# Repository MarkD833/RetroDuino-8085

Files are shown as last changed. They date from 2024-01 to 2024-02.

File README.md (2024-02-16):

# RetroDuino-8085

I've been toying with the idea of creating an 8085 based microprocessor board around the size of an Arduino UNO ever since I came across the [65uino](https://hackaday.io/project/190260-65uino) board on the hackaday website.

# Table of contents
* [The wish list](#the-basics-of-the-design)
  - [The Microprocessor](#the-microprocessor)
  - [ROM](#rom)
  - [RAM](#ram)
  - [Serial](#serial)
  - [I/O](#digital-input-output)
  - [ADC](#analogue-to-digital-converter)
* [Board Layout](#the-board-layout)
* [Assembly Instructions](#assembly-instructions)
* [The 16V8 GAL](#the-16v8-gal)
* [Pinout](#pinout)
* [Software](#software)
* [PCB Files](#the-board-design-files)
* [Known Errors](#known-errors)
* [History](#history)
## The basics of the design

I started off with some basics:
| Item | Notes |
| :---- | :---- |
| Microprocessor | an 8085 device but which one and what clock speed |
| ROM | At least 8K maybe 16K - but do I need that much?  |
| RAM | 32K would be good to aim for |
| Serial | 1 serial port but bit bang or hardware? |
| I/O | Bit programmable i/o |
| Analogue In | A multi channel ADC if there's room |
| LEDs | At least 1 user LED |

Oh, and one other requirement - no surface mount chips or hard to solder parts!

That's quite a lot to cram into the footprint on an Arduino UNO!

After a lot of playing around with an Arduino UNO prototyping board and various chip sockets I came up with a basic design and layout.

## The Microprocessor

The 8085 is mostly seen in a 40-pin DIL package. That's a huge amount of real estate on a footprint the size of an Arduino UNO. I discovered that OKI Semiconductor manufactured an 80C85 in a 44-pin PLCC package (MSM80C85AHGS-2K). After a quick bit of digging I located the datasheet and also a source on ebay that was selling some of the chips as NOS (New Old Stock).

Additional board space is consumed as the 8085 has a multiplexed address and data bus. The lower 8-bits are shared between D0..D7 and A0..A7 and an 8-bit latch (74LS573) is used to capture A0..A7.

Another design challenge is that the 8085 interrupts (if I were to use them) are active high rather than active low! 

The 8085 is clocked from an 11.0592MHz crystal, which gives an actual clock of 5.5296MHz (the 8085 divides the crystal frequency by 2). I've yet to experiment to see the effects of a higher frequency even though I'm exceeding the manufacturers 10MHz clock by 10% already.

## ROM

There are quite a few ROM devices available in a PLCC package as well, but I decided to go with a Winbond W27C512 64K x 8 EEPROM in a 28-pin DIL package. There's plenty for sale on ebay too. The reason for going the DIL package route will become clear with the choice of RAM device.

## RAM

I couldn't find any suitable RAM devices in PLCC format so the project success was looking rather bleak. Then I discovered that there were some SRAM devices available in DIL packages that were only 0.3in wide (called Skinny-DIP if I recall correctly). I then got lucky and sourced some UMC UM61512AK 64K x 8 SRAMs in a skinny 32-pin DIL package.

The RAM chip could sit underneath the ROM chip and I would save a lot of board space.

## Serial

I thought about bit banging the serial port using the SID and SOD pins of the 8085 but decided to try and go with real hardware. Again board space was at a premium so the hunt was on for a small UART device. A lot of serial chips have a large number of pins dedicated to various handshaking signals as well as synchronous data transfer - although some devices allow repurposing of these signals as discrete inputs or outputs. They are all still quite large chips in either PLCC or 0.6in DIL packages.

I then discovered a Philips SCC2691 UART (SCC2691AC1N24) that was available in a 0.3in wide 24-pin DIL package. It had an internal baud rate generator and a single 16-bit timer/counter as well. 

## Digital Input Output

I really wanted the I/O chip to have pin programmable direction control. That ruled out the 8155 and 8255 chips. It took a lot of searching but I then discovered a Zilog Z85C36. It had 2x 8-bit bit programmable I/O ports as well as 3x 16-bit timer/counters. That would be perfect!

Except that it wasn't! In my v1.0 design, I couldn't get the Z85C36 to respond at all. I don't know quite what the issue was as I was sure that I was meeting the timing requirements - but clearly something wasn't right.

In order to salvage the situation, I changed the I/O chip to a WDC W65C22S device. The chip still gave me 2x 8-bit bit programmable I/O ports, but only 2x 16-bit timer/counters.

## Analogue to Digital Converter

If I could fit it in, then an a National Semiconductor ADC0844 might work out - it's a 4 channel ADC in a 20-pin DIL package. 

# The board layout

There was quite a bit of massaging to get everything to fit as I also used a GAL16V8 to handle address decoding and interrupt inversion. The result was a board slightly longer than an Arduino UNO (but the same width).

This is an annotated 3D view of the board generated by Kicad as it stands at v1.2.

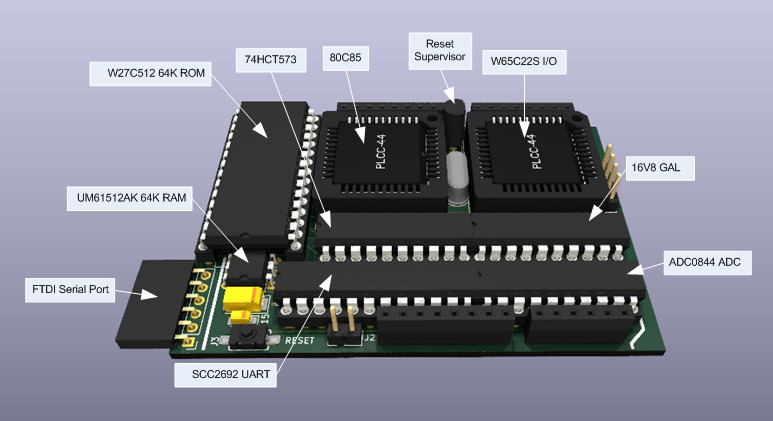
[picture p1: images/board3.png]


The thick white lines on the silkscreen just to the right of the FTDI serial port connector and the ADC0844 chip show the outline of an actual Arduino UNO board.

# Assembly Instructions

Assembly of the board is pretty straightforward with a few things of note.

1. Solder all the small SMD resistors and capacitors first - especially on the top of the board as there is very little room once the IC sockets are fitted.
2. Solder the microprocessor crystal and Reset device before fitting the 44-pin PLCC sockets otherwise you may find that the crystal will not fit down between the 44-pin PLCC sockets. 
3. Depending on the particular DIL socket(s) used for the SCC2691 UART, you may need to remove some of the plastic from the socket so that the 3.6864MHz crystal fits. I used 2 turned-pin sockets, an 8-pin and a 16-pin, to create the 24-pin socket needed. I found that the turned pin socket was less bulky than a regular socket.
4. The 28-pin DIL socket for the W27C512 ROM needs modifying. As the RAM chip will be sitting underneath the ROM chip, I removed the 3 pieces of plastic between the 2 rows of pins - effectively creating two separate 14-pin SIL sockets.
5. Lastly, solder the 4 SIL sockets. These pretty much seal off the top of the board for any further access with a soldering iron, so make sure that the board works before fitting thse. 

This is a photo of the RetroDuino-8085 board showing the location of the 3.6864MHz UART crystal and the modified 28-pin DIL socket.

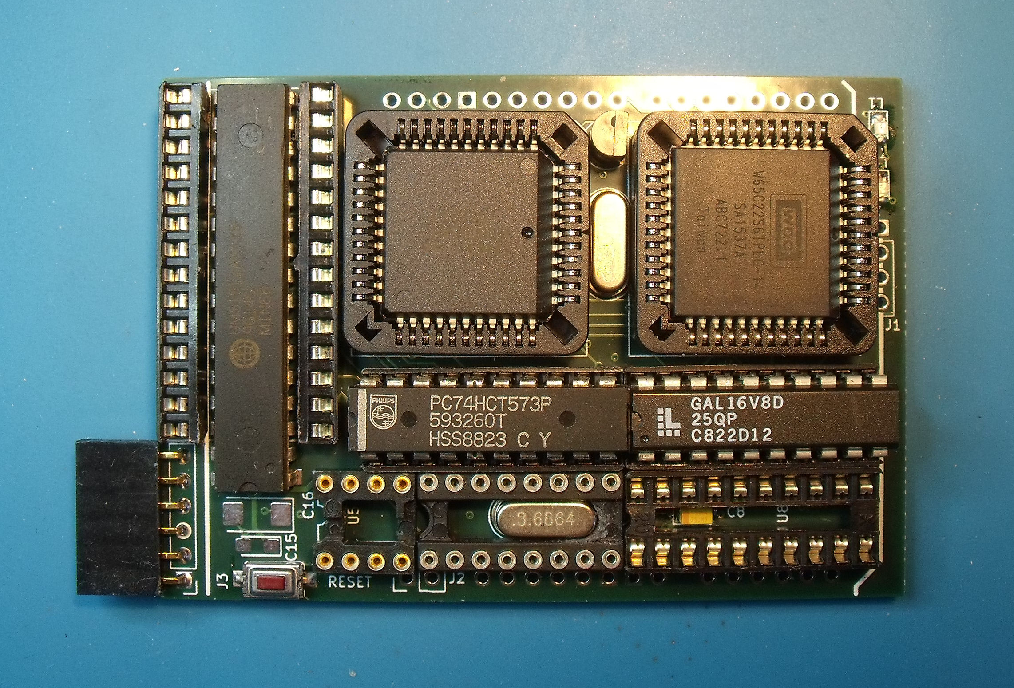
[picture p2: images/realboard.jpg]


# The 16V8 GAL

There's so little space on this board that a GAL seemed the logical choice to handle the usual discrete logic. The GAL does address and i/o decoding as follows:
* Memory space
  * 0x0000 - 0x3FFF selects the ROM
  * 0x4000 - 0xFFFF selets the RAM
* I/O space
  * 0x00 - 0x3F selects the SCC2692 UART
  * 0x40 - 0x7F selects the W65C22S digital i/o chip
  * 0x80 - 0xBF selects the ADC0844 ADC chip
 
In addition, the GAL inverts the SCC2692 and W65C22S interrupt signals.

Finally, the GAL has the ability to completely switch out the ROM to give access to the full 64K or RAM. The 8085 SOD pin is used to control this feature.

The GAL files are in the code folder.

# Pinout
Below is an image of the pinout I'm using - laid out in a similar way to the Arduino pinout diagrams found on the web. Note that the I2C and SPI signals will hopefully be generated by a software implementation of a hardware interface. 

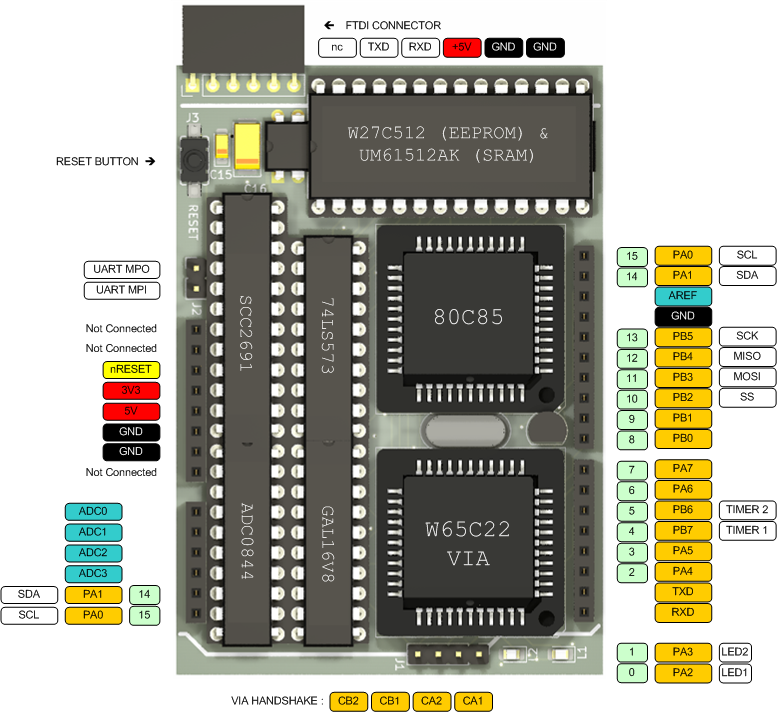
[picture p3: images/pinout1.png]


# Software

Please see the readme in the Code folder for more details on the software.

# The board design files

The board folder holds the gerber files that were sent to JLCPCB to make the board. It's a 4 layer board but small enough to get it made very cheaply.

The design was done using Kicad 7.0. I'm not sure exactly which files I need to share for the schematic and board layout so I've put the .kicad_pro, .kicad_sch & .kicad_sch files into the board folder. There's also the BOM as a CSV file showing the components used.

# Known errors

Yep, there are errors with v1.2. So far:
* LED D2 wrong way round
* LED D3 wrong way round

# History
* v1.2
  * Used ALE to clock the GAL rather than SYSCLK.
  * Removed the CompactFlash socket and associated passives.
  * Used 8085 SOD discrete to switch out the ROM.
  * Addition of 2nd user LED.
  * Repositioning of the FTDI connector.
* v1.1 
  * Updated design using the W65C22 PIA chip.
* v1.0
  * Initial design using the Z85C36 CIO chip.

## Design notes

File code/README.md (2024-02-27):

# RetroDuino-8085 Software

## The 8085 Monitor 
The MON85 folder contains a modified version of the excellent 8085 monitor called MON85 written by [Dave Dunfield](https://dunfield.themindfactory.com/). You can find the source code to the 8085 monitor along with monitors for other micros in the MONITORS.ZIP file on Dave's website. The monitor code needs tweeking to support the specific UART hardware I am using but that simply involves providing code to initialise the UART and code to output a characher/byte as well as read in a character/byte.

MON85 can be assembled using the free online assembler at [ASM80.COM](https://asm80.com) - select the 8080 CPU.

The MON85 user manual is also in the MON85 folder.

I've modified MON85 to work with the SCC2691 UART such that there are 2 versions of MON85 available:

| Software | Notes |
| :---- | :---- |
| MON85_ROM | Monitor runs in ROM and 48K RAM is available from 0x4000 - 0xFFFF. |
| MON85_RAM | Monitor runs in RAM and the whole 64K RAM is available but the monitor resides at 0x0000 - 0x1100. |

In addition, the MON85_ROM version has a small tweak. During initialisation, a small piece of code is copied from the ROM into RAM starting at address 0xFF80. Executing the code from MON85 with a "g FF80" command will disable the ROM (and MON85) and execute code starting at address 0x0000.
  
## A simple LED flasher
The LEDTest folder contains a simple piece of assembler code that flashes the 2 onboard LEDs. The code was assembled using the [ASM80](https://www.asm80.com/) online assembler. Set the CPU type to 8080 when creating the file. I've also put the listing file generated by ASM80 into the LEDTest folder along with the Intel-HEX file that can be loaded using MON85. The code is designed to load at address 0x5000 and run from that address.

## A simple LED flasher in RAM
The LEDTest2 folder contains the same simple LED flashing code as above, BUT demonstates an interesting feature. Note that this code should only be used with the MON85 ROM monitor - it won't work with the MON85 RAM monitor.

The MON85 monitor resides in ROM starting at address 0x0000. The downside of this is usually that you cannot put your own interrupt handlers there as it's Read Only. However, with the RetroDuino-8085 design, you can!

Using the MON85 L command, load the LEDTest2 Intel-HEX file. This will load the LED flashing code into RAM at address 0x0000. Even though the MON85 ROM resides in this area, MON85 can actually write to the RAM at the same address - it just can't read from that RAM. Any attempt to read from this area will read the ROM - i.e MON85.

In order to run the code, give MON85 the command "g FF80". There is a small piece of code that is pre-loaded by MON85 that resides at this address. This simple bit of code sets the 8085 SOD pin high - switching out the MON85 ROM completely - and then jumps to address 0x0000 to execute whatever code it finds there.

You can put whatever code you like into low memory and run it just like it would run from ROM.

The downside is that once the ROM is switched out, you loose all the MON85 capabilities like inspecting and modifying memory, setting breakpoints etc.

# z88dk - The z80 development kit

## A Simple Hello
I've figured out how to use the [z88dk](https://z88dk.org/site/) suite to create some code for the RetroDuino-8085. I'm completely new to the z88dk tools so look away now if you've already got experience of using z88dk as what follows might not be pretty! Expect dragons!

The traditional ["Hello World"](https://en.wikipedia.org/wiki/%22Hello,_World!%22_program) code was created by following the [Classic Homebrew](https://github.com/z88dk/z88dk/wiki/Classic--Homebrew) hardware quick start guide and includes console input. As the RetroDuino-8085 can run code from address 0x0000, I've also got a basic crt0 file as well. It's all in the simple_hello folder along with the batch file I used to build the code.

Use the MON85 L command to load the Intel-HEX file and then give MON85 the command "g FF80" to switch out the ROM and run the code.

## Some more useful software
After a bit of experimentaion, I now have a software SPI interface and a software I2C interface. The code is in the z88dk spi-i2c folder.

There's a sys folder now that includes the following:
| File | Description |
| :---- | :---- |
| hardware.c | c source file that handles SPI, I2C & the UART timer |
| hardware.h | function prototypes |
| low_level.asm | low level assembler functions
| rd85_crt0.asm | startup code for the RetroDuino-8085|

I've also included 3 example programs - main_timer.c, main_spi.c and main_i2c.c which show how to use the software SPI, software I2C and the system tick (currently set to increment every 20mS).

Rename the main_*.c file to simply main.c and the build script should work to demonstrate SPI, I2C or system tick.

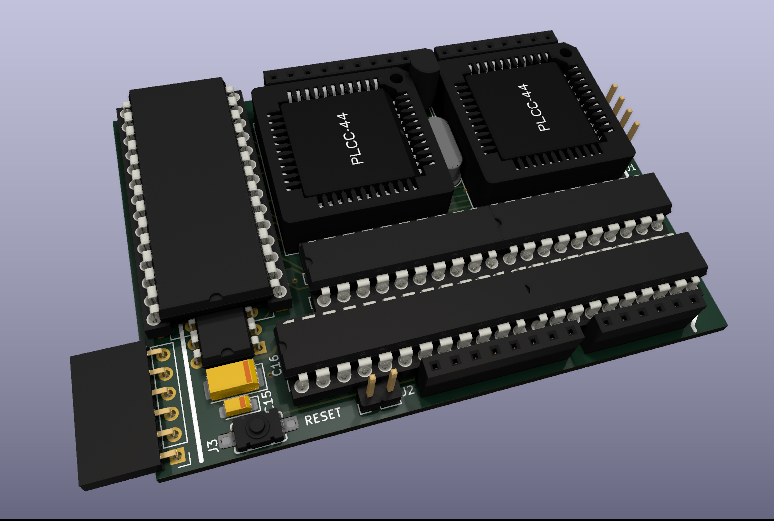
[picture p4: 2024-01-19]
images/board1.png

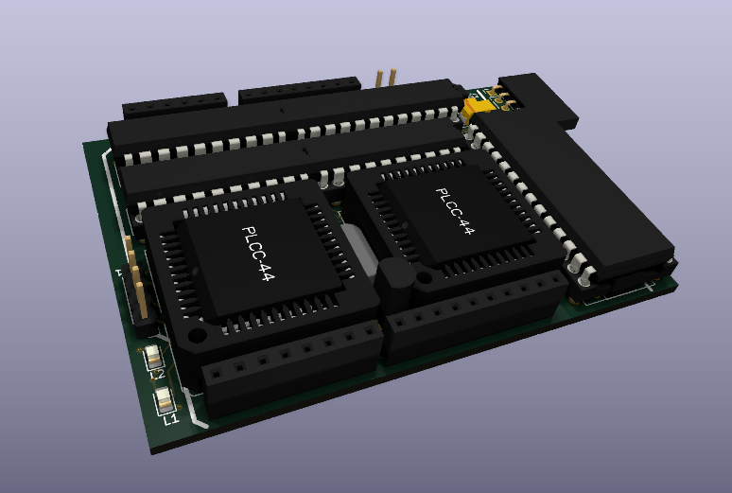
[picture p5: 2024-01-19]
images/board2.png

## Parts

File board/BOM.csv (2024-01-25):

Source: | D:\KiCad_Projects\0025_8085_UNO_Board_W65C22_v2\0025_8085_UNO_Board_W65C22_v2.kicad_sch
Date: | 25/01/2024 17:21:43
Tool: | Eeschema 7.0.5
Generator: | D:\Program Files\KiCad\7.0\bin\scripting\plugins/bom_csv_grouped_by_value.py
Component Count: | 42
Collated Components:
Item | Qty | Reference(s) | Value | LibPart | Footprint | Datasheet | DNP
1 | 1 | A1 | Arduino_Uno_R3_Shield | MyLibrary2023:Arduino_Uno_R3_Shield | MyLibrary2023:Arduino_Uno_8085_Base_1
2 | 9 | C1, C2, C3, C4, C5, C6, C7, C9, C14 | 100n | Device:C | Capacitor_SMD:C_0603_1608Metric_Pad1.08x0.95mm_HandSolder | ~
3 | 1 | C8 | 10u | Device:C_Polarized | Capacitor_Tantalum_SMD:CP_EIA-3216-18_Kemet-A | ~
4 | 4 | C10, C11, C12, C13 | 22p | Device:C | Capacitor_SMD:C_0603_1608Metric_Pad1.08x0.95mm_HandSolder | ~
5 | 1 | C15 | 10u | Device:C_Polarized | Capacitor_Tantalum_SMD:CP_EIA-3216-18_Kemet-A_Pad1.58x1.35mm_HandSolder | ~
6 | 1 | C16 | 22u | Device:C_Polarized | Capacitor_Tantalum_SMD:CP_EIA-6032-28_Kemet-C | ~
7 | 2 | D2, D3 | LED | Device:LED | LED_SMD:LED_0805_2012Metric_Pad1.15x1.40mm_HandSolder | ~
8 | 1 | J1 | Conn_01x04 | Connector_Generic:Conn_01x04 | Connector_PinHeader_2.54mm:PinHeader_1x04_P2.54mm_Vertical | ~
9 | 1 | J2 | ~ | Connector_Generic:Conn_01x02 | Connector_PinHeader_2.54mm:PinHeader_1x02_P2.54mm_Vertical | ~
10 | 1 | J3 | ~ | Connector_Generic:Conn_01x06 | Connector_PinHeader_2.54mm:PinHeader_1x06_P2.54mm_Vertical | ~
11 | 3 | R1, R2, R12 | 10K | Device:R | Resistor_SMD:R_0805_2012Metric_Pad1.20x1.40mm_HandSolder | ~
12 | 2 | R7, R8 | 4K7 | Device:R | Resistor_SMD:R_0805_2012Metric_Pad1.20x1.40mm_HandSolder | ~
13 | 2 | R9, R10 | 1K | Device:R | Resistor_SMD:R_0805_2012Metric_Pad1.20x1.40mm_HandSolder | ~
14 | 1 | SW1 | SW_Push | Switch:SW_Push | MyLibrary2023:TACTILE_SWITCH_SMD_6.0X3.5MM | ~
15 | 1 | U1 | MSM80C85AH | MyLibrary2023:MSM80C85AH | Package_LCC:PLCC-44_THT-Socket
16 | 1 | U2 | 74LS573 | 74xx:74LS573 | Package_DIP:DIP-20_W7.62mm | 74xx/74hc573.pdf
17 | 1 | U3 | GAL16V8 | Logic_Programmable:GAL16V8 | Package_DIP:DIP-20_W7.62mm
18 | 1 | U4 | W65C22x6TPL | MyLibrary2023:W65C22x6TPL | Package_LCC:PLCC-44_THT-Socket
19 | 1 | U5 | SCC2691AC1N24 | MyLibrary2023:SCC2691AC1N24 | Package_DIP:DIP-24_W7.62mm
20 | 1 | U6 | UM61512AK | MyLibrary2023:UM61512AK | Package_DIP:DIP-32_W7.62mm
21 | 1 | U7 | W27C512 | MyLibrary2023:W27C512 | Package_DIP:DIP-28_W15.24mm
22 | 1 | U8 | ADC0844 | MyLibrary2023:ADC0844 | Package_DIP:DIP-20_W7.62mm
23 | 1 | U9 | DS1233-10 | MyLibrary2023:DS1233 | Package_TO_SOT_THT:TO-92L_Inline
24 | 1 | U10 | AMS1117-3.3 | Regulator_Linear:AMS1117-3.3 | Package_TO_SOT_SMD:SOT-223-3_TabPin2 | http://www.advanced-monolithic.com/pdf/ds1117.pdf
25 | 1 | Y1 | 11.0592MHz | Device:Crystal | Crystal:Crystal_HC49-U_Vertical | ~
26 | 1 | Y2 | 3.6864MHz | Device:Crystal | Crystal:Crystal_HC49-U_Vertical | ~

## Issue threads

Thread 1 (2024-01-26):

LEDs incorrectly wired

MarkD833, 2024-01-26:
User LEDs D2 and D3 (connected to pins PA2 and PA3) are shown the wrong way round in the schematic.

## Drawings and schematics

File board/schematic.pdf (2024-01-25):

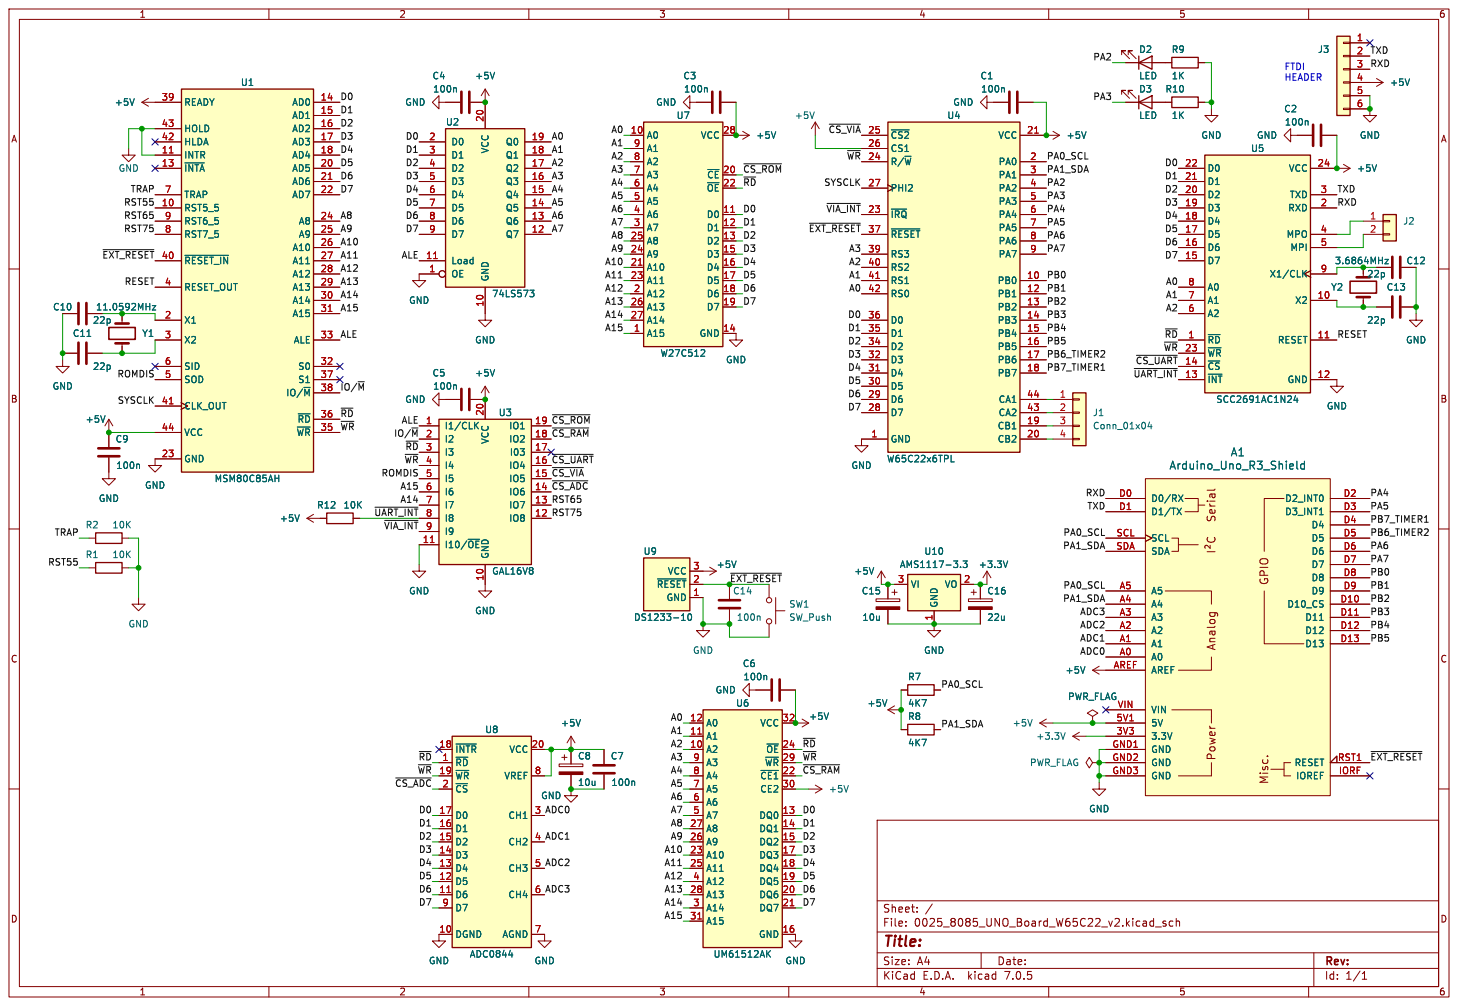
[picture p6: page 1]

Id: 1/1 Title: File: 0025_8085_UNO_Board_W65C22_v2.kicad_sch Sheet: /

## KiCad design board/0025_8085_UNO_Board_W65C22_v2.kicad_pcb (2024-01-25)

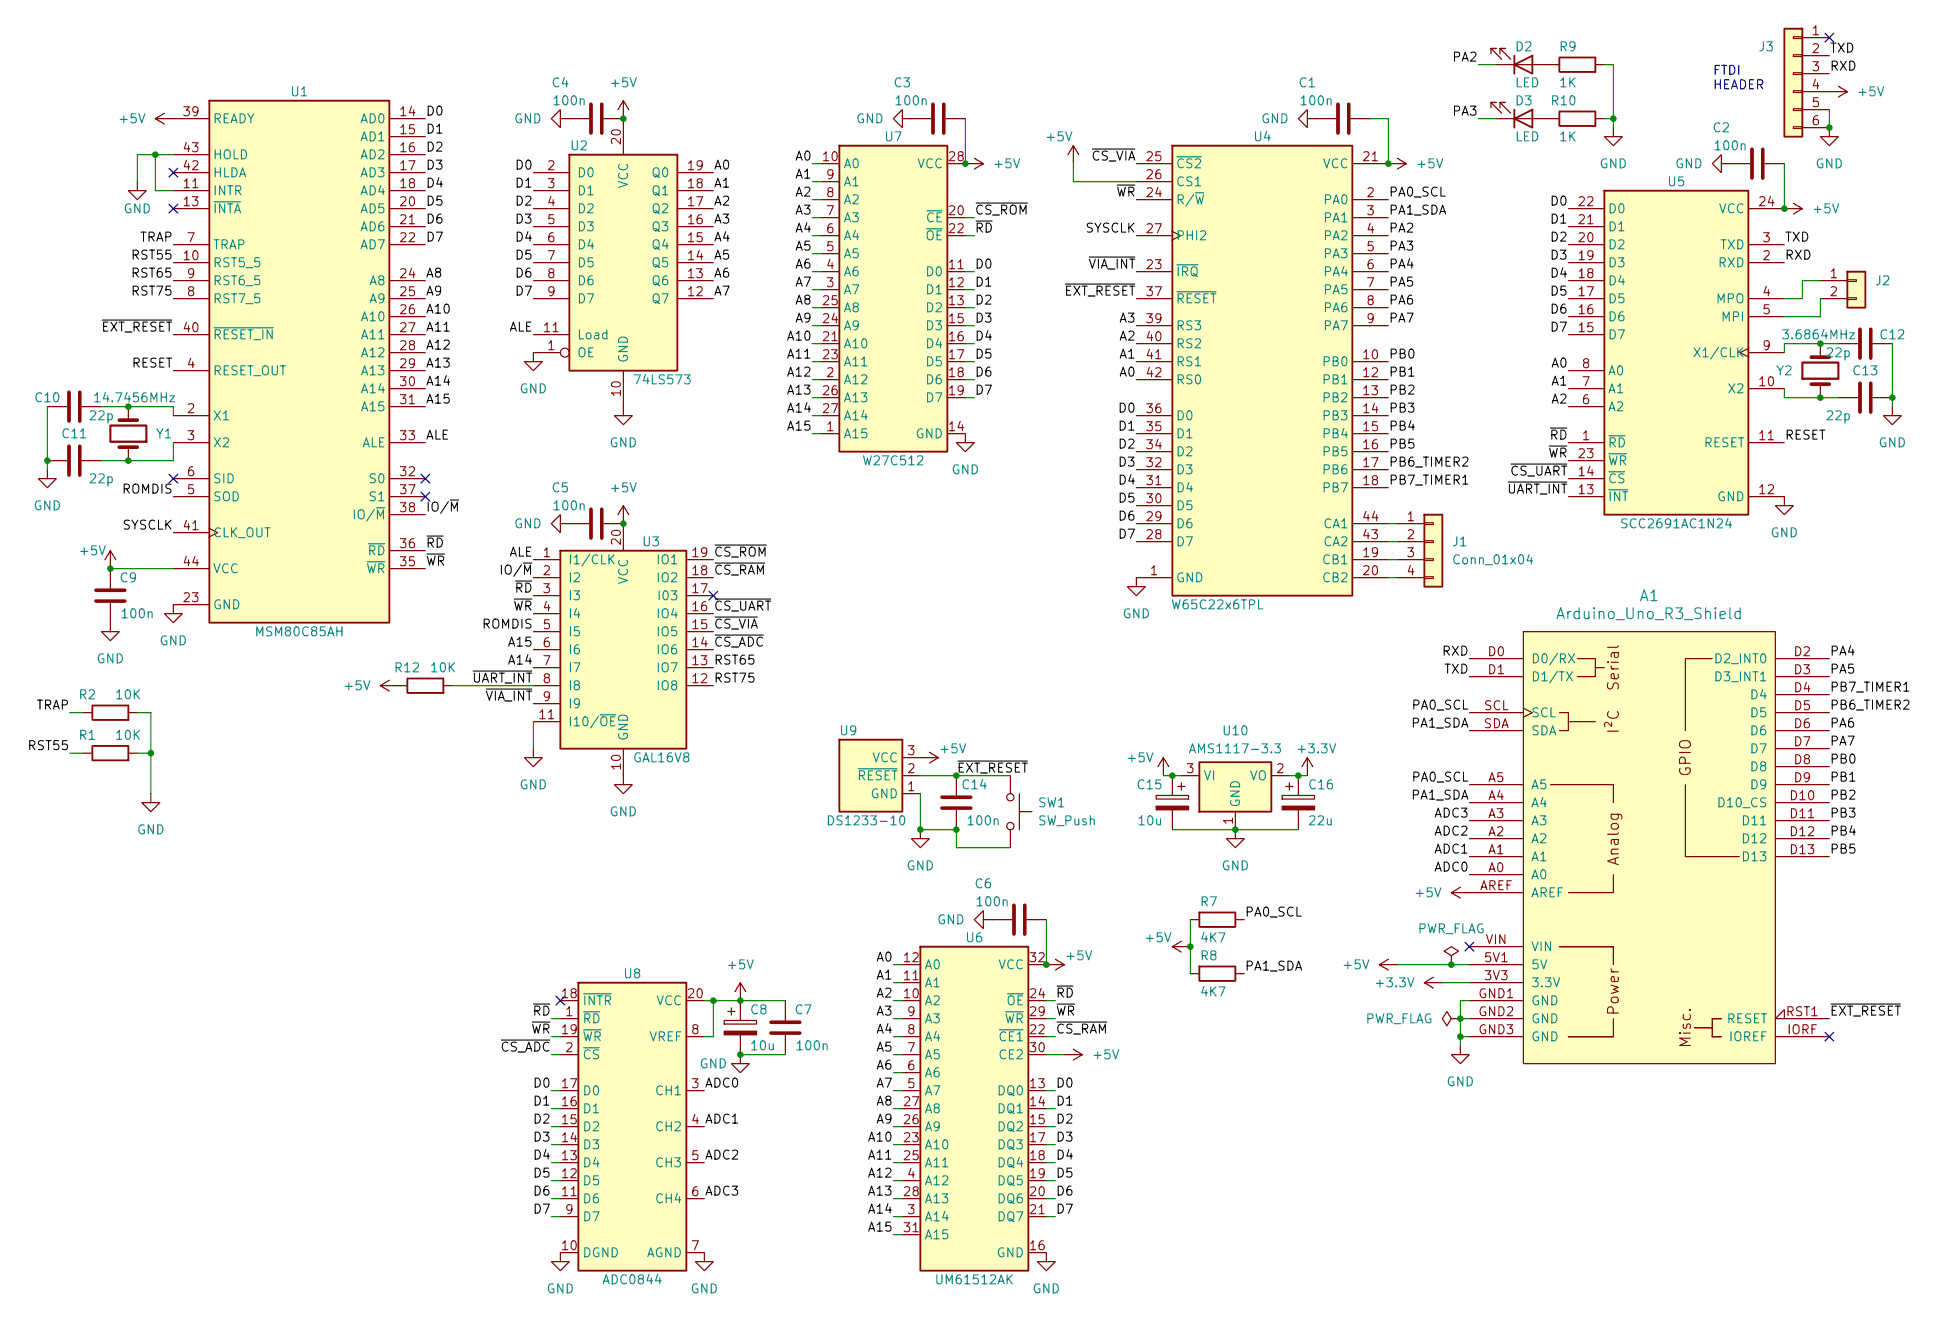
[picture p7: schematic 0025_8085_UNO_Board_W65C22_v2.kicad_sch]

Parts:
A1: Arduino_Uno_R3_Shield; Arduino_Uno_8085_Base_1
C1, C2, C3, C4, C5, C6, C7, C9, C14: 100n; C_0603_1608Metric_Pad1.08x0.95mm_HandSolder
C8: 10u; CP_EIA-3216-18_Kemet-A
C10, C11, C12, C13: 22p; C_0603_1608Metric_Pad1.08x0.95mm_HandSolder
C15: 10u; CP_EIA-3216-18_Kemet-A_Pad1.58x1.35mm_HandSolder
C16: 22u; CP_EIA-6032-28_Kemet-C
D2, D3: LED; LED_0805_2012Metric_Pad1.15x1.40mm_HandSolder
J1: Conn_01x04; PinHeader_1x04_P2.54mm_Vertical
J2: PinHeader_1x02_P2.54mm_Vertical
J3: PinHeader_1x06_P2.54mm_Vertical
R1, R2, R12: 10K; R_0805_2012Metric_Pad1.20x1.40mm_HandSolder
R7, R8: 4K7; R_0805_2012Metric_Pad1.20x1.40mm_HandSolder
R9, R10: 1K; R_0805_2012Metric_Pad1.20x1.40mm_HandSolder
SW1: SW_Push; TACTILE_SWITCH_SMD_6.0X3.5MM
U1: MSM80C85AH; PLCC-44_THT-Socket
U2: 74LS573; DIP-20_W7.62mm
U3: GAL16V8; DIP-20_W7.62mm
U4: W65C22x6TPL; PLCC-44_THT-Socket
U5: SCC2691AC1N24; DIP-24_W7.62mm
U6: UM61512AK; DIP-32_W7.62mm
U7: W27C512; DIP-28_W15.24mm
U8: ADC0844; DIP-20_W7.62mm
U9: DS1233-10; TO-92L_Inline
U10: AMS1117-3.3; SOT-223-3_TabPin2
Y1: 14.7456MHz; Crystal_HC49-U_Vertical
Y2: 3.6864MHz; Crystal_HC49-U_Vertical

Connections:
+3.3V: A1.3V3 (3.3V), C16.1, U10.2 (VO)
+5V: A1.5V1 (5V), A1.AREF, C1.2, C2.2, C3.2, C4.2, C5.2, C6.2, C7.1, C8.1, C9.1, C15.1, J3.4, R7.2, R8.2, R12.1, U1.39 (READY), U1.44 (VCC), U2.20 (VCC), U3.20 (VCC), U4.21 (VCC), U4.26 (CS1), U5.24 (VCC), U6.30 (CE2), U6.32 (VCC), U7.28 (VCC), U8.8 (VREF), U8.20 (VCC), U9.3 (VCC), U10.3 (VI)
/A0: U2.19 (Q0), U4.42 (RS0), U5.8 (A0), U6.12 (A0), U7.10 (A0)
/A1: U2.18 (Q1), U4.41 (RS1), U5.7 (A1), U6.11 (A1), U7.9 (A1)
/A2: U2.17 (Q2), U4.40 (RS2), U5.6 (A2), U6.10 (A2), U7.8 (A2)
/A3: U2.16 (Q3), U4.39 (RS3), U6.9 (A3), U7.7 (A3)
/A4: U2.15 (Q4), U6.8 (A4), U7.6 (A4)
/A5: U2.14 (Q5), U6.7 (A5), U7.5 (A5)
/A6: U2.13 (Q6), U6.6 (A6), U7.4 (A6)
/A7: U2.12 (Q7), U6.5 (A7), U7.3 (A7)
/A8: U1.24 (A8), U6.27 (A8), U7.25 (A8)
/A9: U1.25 (A9), U6.26 (A9), U7.24 (A9)
/A10: U1.26 (A10), U6.23 (A10), U7.21 (A10)
/A11: U1.27 (A11), U6.25 (A11), U7.23 (A11)
/A12: U1.28 (A12), U6.4 (A12), U7.2 (A12)
/A13: U1.29 (A13), U6.28 (A13), U7.26 (A13)
/A14: U1.30 (A14), U3.7 (I7), U6.3 (A14), U7.27 (A14)
/A15: U1.31 (A15), U3.6 (I6), U6.31 (A15), U7.1 (A15)
/ADC0: A1.A0, U8.3 (CH1)
/ADC1: A1.A1, U8.4 (CH2)
/ADC2: A1.A2, U8.5 (CH3)
/ADC3: A1.A3, U8.6 (CH4)
/ALE: U1.33 (ALE), U2.11 (Load), U3.1 (I1/CLK)
/D0: U1.14 (AD0), U2.2 (D0), U4.36 (D0), U5.22 (D0), U6.13 (DQ0), U7.11 (D0), U8.17 (D0)
/D1: U1.15 (AD1), U2.3 (D1), U4.35 (D1), U5.21 (D1), U6.14 (DQ1), U7.12 (D1), U8.16 (D1)
/D2: U1.16 (AD2), U2.4 (D2), U4.34 (D2), U5.20 (D2), U6.15 (DQ2), U7.13 (D2), U8.15 (D2)
/D3: U1.17 (AD3), U2.5 (D3), U4.32 (D3), U5.19 (D3), U6.17 (DQ3), U7.15 (D3), U8.14 (D3)
/D4: U1.18 (AD4), U2.6 (D4), U4.31 (D4), U5.18 (D4), U6.18 (DQ4), U7.16 (D4), U8.13 (D4)
/D5: U1.20 (AD5), U2.7 (D5), U4.30 (D5), U5.17 (D5), U6.19 (DQ5), U7.17 (D5), U8.12 (D5)
/D6: U1.21 (AD6), U2.8 (D6), U4.29 (D6), U5.16 (D6), U6.20 (DQ6), U7.18 (D6), U8.11 (D6)
/D7: U1.22 (AD7), U2.9 (D7), U4.28 (D7), U5.15 (D7), U6.21 (DQ7), U7.19 (D7), U8.9 (D7)
/IO/~M: U1.38 (IO/~M), U3.2 (I2)
/PA0_SCL: A1.A5, A1.SCL, R7.1, U4.2 (PA0)
/PA1_SDA: A1.A4, A1.SDA, R8.1, U4.3 (PA1)
/PA2: D2.1 (K), U4.4 (PA2)
/PA3: D3.1 (K), U4.5 (PA3)
/PA4: A1.D2 (D2_INT0), U4.6 (PA4)
/PA5: A1.D3 (D3_INT1), U4.7 (PA5)
/PA6: A1.D6, U4.8 (PA6)
/PA7: A1.D7, U4.9 (PA7)
/PB0: A1.D8, U4.10 (PB0)
/PB1: A1.D9, U4.12 (PB1)
/PB2: A1.D10 (D10_CS), U4.13 (PB2)
/PB3: A1.D11, U4.14 (PB3)
/PB4: A1.D12, U4.15 (PB4)
/PB5: A1.D13, U4.16 (PB5)
/PB6_TIMER2: A1.D5, U4.17 (PB6)
/PB7_TIMER1: A1.D4, U4.18 (PB7)
/RESET: U1.4 (RESET_OUT), U5.11 (RESET)
/ROMDIS: U1.5 (SOD), U3.5 (I5)
/RST55: R1.1, U1.10 (RST5_5)
/RST65: U1.9 (RST6_5), U3.13 (IO7)
/RST75: U1.8 (RST7_5), U3.12 (IO8)
/RXD: A1.D0 (D0/RX), J3.3, U5.2 (RXD)
/SYSCLK: U1.41 (CLK_OUT), U4.27 (PHI2)
/TRAP: R2.1, U1.7 (TRAP)
/TXD: A1.D1 (D1/TX), J3.2, U5.3 (TXD)
/~CS_ADC: U3.14 (IO6), U8.2 (~CS)
/~CS_RAM: U3.18 (IO2), U6.22 (~CE1)
/~CS_ROM: U3.19 (IO1), U7.20 (~CE)
/~CS_UART: U3.16 (IO4), U5.14 (~CS)
/~CS_VIA: U3.15 (IO5), U4.25 (~CS2)
/~EXT_RESET: A1.RST1 (RESET), C14.1, SW1.1, U1.40 (~RESET_IN), U4.37 (~RESET), U9.2 (~RESET)
/~RD: U1.36 (~RD), U3.3 (I3), U5.1 (~RD), U6.24 (~OE), U7.22 (~OE), U8.1 (~RD)
/~UART_INT: R12.2, U3.8 (I8), U5.13 (~INT)
/~VIA_INT: U3.9 (I9), U4.23 (~IRQ)
/~WR: U1.35 (~WR), U3.4 (I4), U4.24 (R/~W), U5.23 (~WR), U6.29 (~WR), U8.19 (~WR)
GND: A1.GND1 (GND), A1.GND2 (GND), A1.GND3 (GND), C1.1, C2.1, C3.1, C4.1, C5.1, C6.1, C7.2, C8.2, C9.2, C10.1, C11.2, C12.1, C13.2, C14.2, C15.2, C16.2, J3.5, J3.6, R1.2, R2.2, R9.2, R10.2, SW1.2, U1.11 (INTR), U1.23 (GND), U1.43 (HOLD), U2.1 (OE), U2.10 (GND), U3.10 (GND), U3.11 (I10/~OE), U4.1 (GND), U5.12 (GND), U6.16 (GND), U7.14 (GND), U8.7 (AGND), U8.10 (DGND), U9.1 (GND), U10.1 (GND)
unnamed: D2.2 (A), R9.1
unnamed: D3.2 (A), R10.1
unnamed: J1.1, U4.44 (CA1)
unnamed: J1.2, U4.43 (CA2)
unnamed: J1.3, U4.19 (CB1)
unnamed: J1.4, U4.20 (CB2)
unnamed: J2.1, U5.4 (MPO)
unnamed: J2.2, U5.5 (MPI)
unnamed: C10.2, U1.2 (X1), Y1.2
unnamed: C11.1, U1.3 (X2), Y1.1
unnamed: C12.2, U5.9 (X1/CLK), Y2.2
unnamed: C13.1, U5.10 (X2), Y2.1

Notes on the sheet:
FTDI HEADER

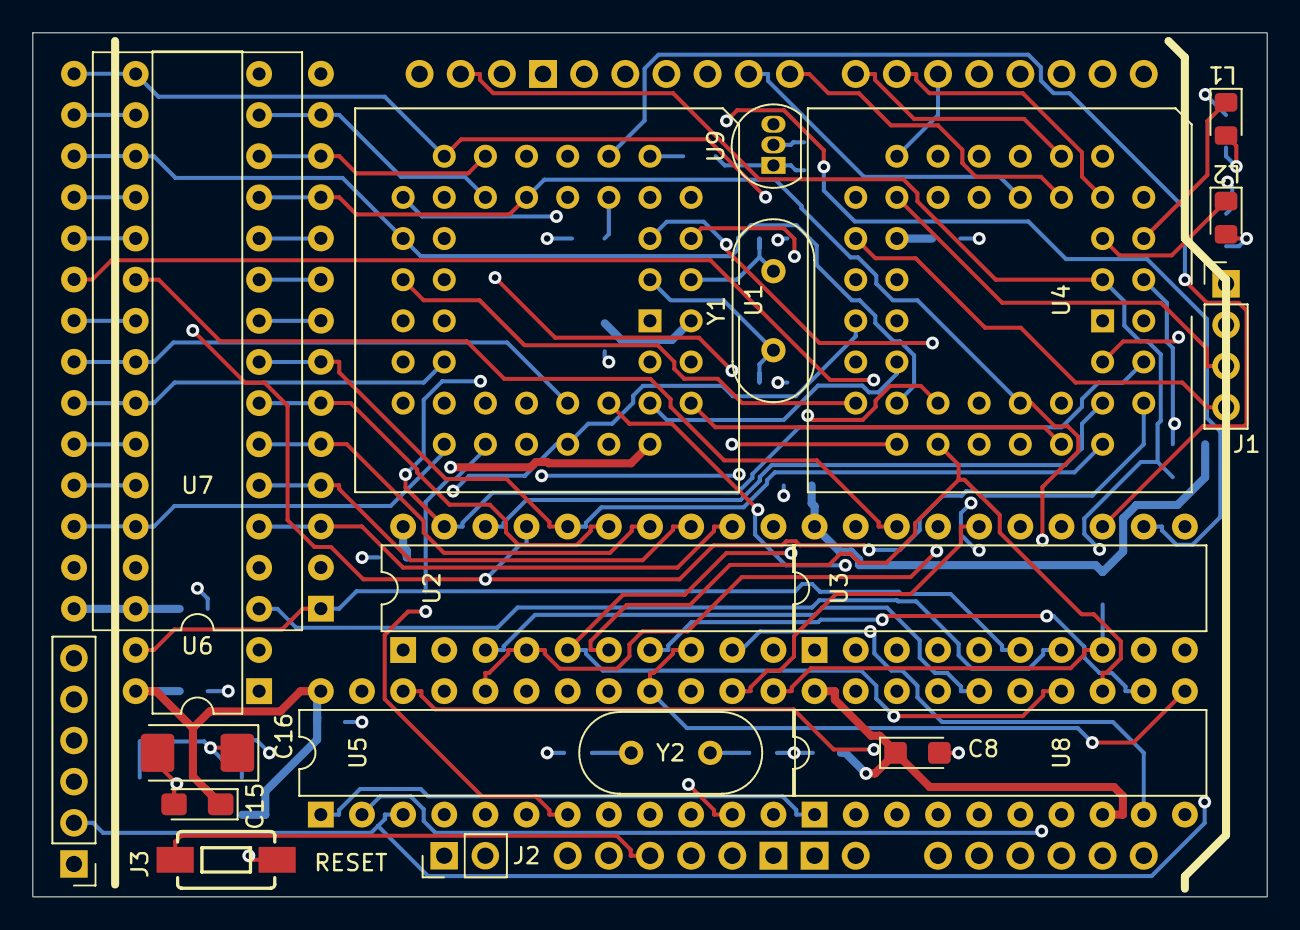
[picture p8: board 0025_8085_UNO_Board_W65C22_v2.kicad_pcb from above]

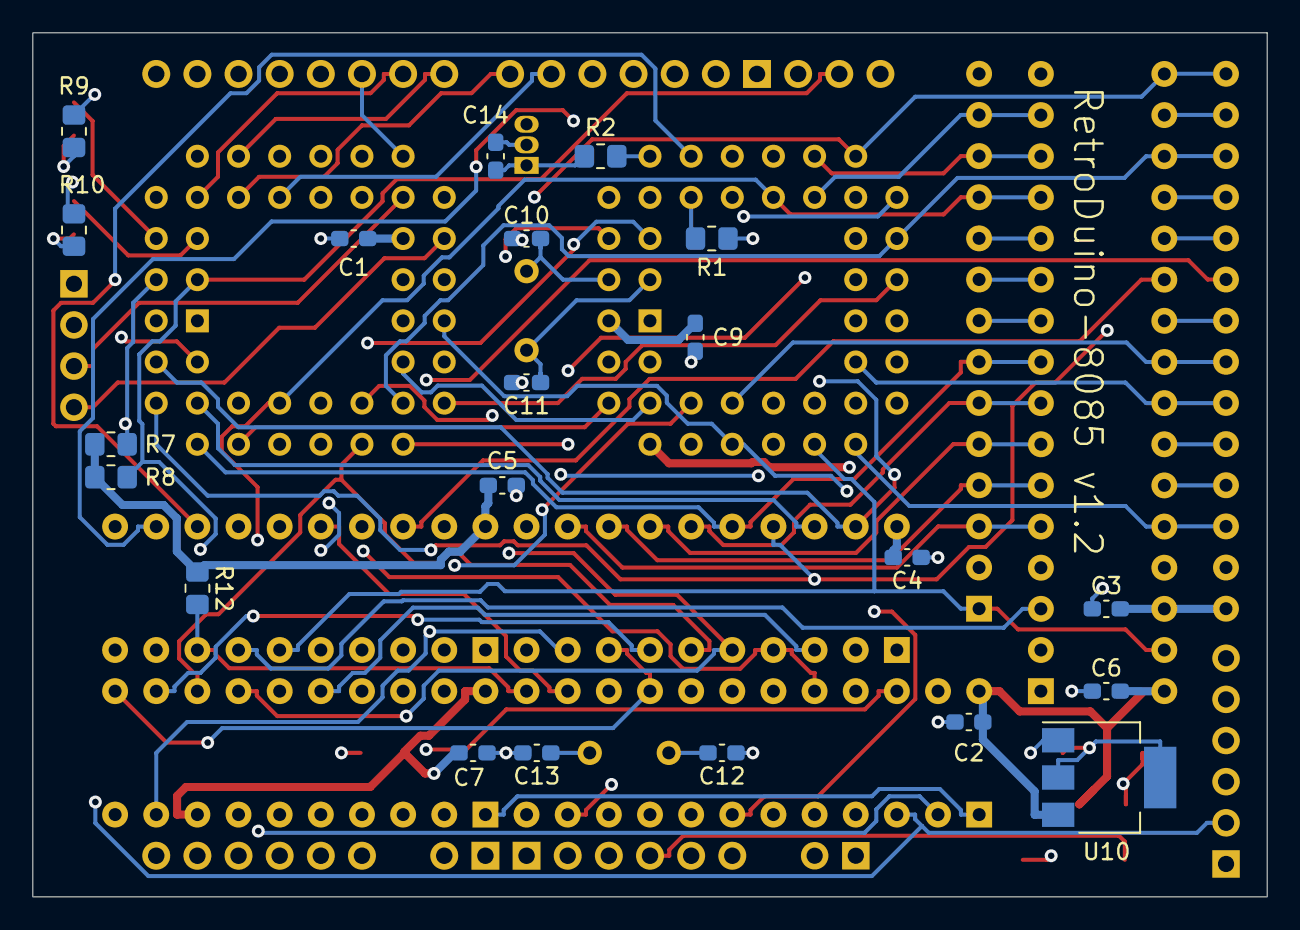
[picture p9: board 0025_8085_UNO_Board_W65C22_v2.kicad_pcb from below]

Board: 4 copper layers, 76.2 x 53.3 mm, 42 parts (21 on the bottom side), 80 nets.

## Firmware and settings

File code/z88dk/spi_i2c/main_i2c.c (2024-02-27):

/* Simple Text I/O for RetroDuino-8085 using z88dk
 *
 * Designed to be loaded via MON85 and assumes that the UART
 * is already configured.
 *
 * Guidance: https://github.com/z88dk/z88dk/wiki/Classic--Homebrew
 */
 
#include <stdio.h>
#include "sys/hardware.h"

void bigDelay( void );

uint8_t toggle = 0;
uint8_t temp[10];
uint8_t v1 = 0;
uint8_t v2 = 0;

int main()
{
    printf("Hello from z88dk!\n");

	pinDir( LED_BUILTIN1, OUTPUT );
	pinWrite( LED_BUILTIN1, 0 );
	
	i2cSetup();
	
    while ( 1 ) {
        int c = getchar();
        printf("Writing 0xAA & 0x55 to RTC RAM at address 0x10\n");

		temp[0] = i2cStart( ( 0x68 << 1 ) | 0x00 );
		temp[1] = i2cWriteByte( 0x10 );
		temp[2] = i2cWriteByte( 0xAA );
		temp[3] = i2cWriteByte( 0x55 );
		i2cStop();

		printf("ACK / NACK values were: ");
		for( uint8_t i=0; i<4; i++) {
			printf("%02X ", temp[i]);
		}
		printf("\n");
		
        printf("Now setting read back pointer to RTC RAM at address 0x10\n");
		/* write out the address to read from */
		temp[0] = i2cStart( ( 0x68 << 1 ) | 0x00 );
		temp[1] = i2cWriteByte( 0x10 );
		i2cStop();
		printf("ACK / NACK values were: %02X %02X\n", temp[0], temp[1] );

        printf("Now reading back 2 bytes from RTC RAM at address 0x10\n");
		temp[0] = i2cStart( ( 0x68 << 1 ) | 0x01 );
		temp[1] = i2cReadByte( 0 );
		temp[2] = i2cReadByte( 1 );
		i2cStop();

		printf("ACK / NACK value for receive was: %02X\n", temp[0]);
		printf("Received bytes were: %02X & %02X\n", temp[1], temp[2]);
			
		toggle++;
		if (( toggle & 0x01 ) == 0) {
			pinWrite( LED_BUILTIN1, 0 );
		} else {
			pinWrite( LED_BUILTIN1, 1 );
		}
    }
}

void bigDelay( void )
{
__asm

    mvi     a,$00       ; silly delay to let port bits settle
delay:
    nop
    nop
    dcr     a
    jnz     delay
	
__endasm
}

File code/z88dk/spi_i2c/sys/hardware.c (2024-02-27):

#include <stdint.h>
#include "common.h"
#include "hardware.h"

#define UART_BASE_ADDR	0x00
#define VIA_BASE_ADDR	0x40
#define ADC_BASE_ADDR	0x80


/******************************************************************************
ADC0844 Analogue to Digital Converter
******************************************************************************/
__sfr __at ADC_BASE_ADDR ADC_REG;	// single register of the ADC_BASE


/******************************************************************************
W65C22S Versatile Interface Adapter
******************************************************************************/
__sfr __at VIA_BASE_ADDR+0x00 VIA_PORTB;		// Port B input/output register
__sfr __at VIA_BASE_ADDR+0x01 VIA_PORTA;		// Port A input/output register
__sfr __at VIA_BASE_ADDR+0x02 VIA_DDRB;			// Port B data direction register
__sfr __at VIA_BASE_ADDR+0x03 VIA_DDRA;			// Port A data direction register
__sfr __at VIA_BASE_ADDR+0x04 VIA_T1C_LOW;		// Timer 1 counter low byte
__sfr __at VIA_BASE_ADDR+0x05 VIA_T1C_HIGH;		// Timer 1 counter high byte
__sfr __at VIA_BASE_ADDR+0x06 VIA_T1L_LOW;		// Timer 1 latch low byte
__sfr __at VIA_BASE_ADDR+0x07 VIA_T1L_HIGH;		// Timer 1 latch high byte
__sfr __at VIA_BASE_ADDR+0x08 VIA_T2C_LOW;		// Timer 2 counter low byte
__sfr __at VIA_BASE_ADDR+0x09 VIA_T2C_HIGH;		// Timer 2 counter high byte
__sfr __at VIA_BASE_ADDR+0x0A VIA_SR;			// Shift register
__sfr __at VIA_BASE_ADDR+0x0B VIA_ACR;			// Aux control register
__sfr __at VIA_BASE_ADDR+0x0C VIA_PCR;			// Peripheral control register
__sfr __at VIA_BASE_ADDR+0x0D VIA_IFR;			// Interrupt flag register
__sfr __at VIA_BASE_ADDR+0x0E VIA_IER;			// Interrupt enable register
__sfr __at VIA_BASE_ADDR+0x0F VIA_ALTPORTA;		// Port A alternate input/output register


/******************************************************************************
SCC2691 Single Channel UART
******************************************************************************/
__sfr __at UART_BASE_ADDR+0x00 UART_MODE;		// R/W : Mode Register #1 & #2
__sfr __at UART_BASE_ADDR+0x01 UART_STATUS;		//  R  : Status Register
__sfr __at UART_BASE_ADDR+0x01 UART_CLKSEL;		//  W  : Clock Select Register
__sfr __at UART_BASE_ADDR+0x02 UART_BRGTEST;	//  R  : Baud Rate Generator Test
__sfr __at UART_BASE_ADDR+0x02 UART_COMMAND;	//  W  : Command Register
__sfr __at UART_BASE_ADDR+0x03 UART_RXDATA;		//  R  : Rx Data Register
__sfr __at UART_BASE_ADDR+0x03 UART_TXDATA;		//  W  : Tx Data Register
__sfr __at UART_BASE_ADDR+0x04 UART_1X16XTEST;	//  R  : 1x/16x Test Register
__sfr __at UART_BASE_ADDR+0x04 UART_AUXCTRL;	//  W  : Aux Control Register
__sfr __at UART_BASE_ADDR+0x05 UART_INTSTAT;	//  R  : Interrupt Status Register
__sfr __at UART_BASE_ADDR+0x05 UART_INTMASK;	//  W  : Interrupt Mask Register
__sfr __at UART_BASE_ADDR+0x06 UART_CTHIGH;		// R/W : Counter/Timer bits 8..15 Register
__sfr __at UART_BASE_ADDR+0x07 UART_CTLOW;		// R/W : Counter/Timer bits 0..7 Register


/******************************************************************************
    #     #     #     #     #        #######   #####   #     #  ####### 
   # #    ##    #    # #    #        #     #  #     #  #     #  #       
  #   #   # #   #   #   #   #        #     #  #        #     #  #       
 #     #  #  #  #  #     #  #        #     #  #  ####  #     #  #####   
 #######  #   # #  #######  #        #     #  #     #  #     #  #       
 #     #  #    ##  #     #  #        #     #  #     #  #     #  #       
 #     #  #     #  #     #  #######  #######   #####    #####   ####### 
*******************************************************************************
* ADC0844 Analogue to Digital Converter
*******************************************************************************
*/

/* adcRead - read the result of a previously started conversion
 */
uint8_t adcRead( void )
{
	return ADC_REG;
}

/* adcStartConversion - initiate an A2D measuring cycle
 */
void adcStartConversion( uint8_t ch )
{
	if (ch > 3) return;

	ADC_REG = ch | 0x40;
}

/******************************************************************************
 ######   ###   #####   ###  #######     #     #       
 #     #   #   #     #   #      #       # #    #       
 #     #   #   #         #      #      #   #   #       
 #     #   #   #  ####   #      #     #     #  #       
 #     #   #   #     #   #      #     #######  #       
 #     #   #   #     #   #      #     #     #  #       
 ######   ###   #####   ###     #     #     #  ####### 
*******************************************************************************
* W65C22S Versatile Interface Adapter
*******************************************************************************
*/

/* Pin map shows which VIA port and mask is needed to set/clear a header pin.
 * It also shows which data direction register is required to set a header pin direction.
 *
 * Port value:
 * 1st byte is added to VIA_PORTB to get the actual port address
 * 2nd byte is used to set/clear the port pin
 *
 * Direction: 
 * 1st byte is added to VIA_DDRB to get the actual port address
 * 2nd byte is used to set/clear the port direction
 */
#define MAXPINS 16
static uint8_t pinMap[ MAXPINS ][2] = {
	{1, 0x04}, {1, 0x08}, {1, 0x10}, {1, 0x20},    /* pins  0 .. 3  */
	{0, 0x80}, {0, 0x40}, {1, 0x40}, {1, 0x80},    /* pins  4 .. 7  */
	{0, 0x01}, {0, 0x02}, {0, 0x04}, {0, 0x08},    /* pins  8 .. 11 */
   	{0, 0x10}, {0, 0x20}, {1, 0x02}, {1, 0x01}     /* pins 12 .. 15 */
};

/******************************************************************************
* pinRead - return the state of a pin
* ----------------------------------------------------------------------------
* pin    : pin number from 0 to 15
* return : 0=>LOW, 1=>HIGH
******************************************************************************/
uint8_t pinRead(uint8_t pin)
{
	if (pin >= MAXPINS) return;
}

/******************************************************************************
* pinWrite - set a pin HIGH or LOW
* ----------------------------------------------------------------------------
* pin : pin number from 0 to 15
* val : 0=>LOW, !0=>HIGH
******************************************************************************/
void pinWrite(uint8_t pin, uint8_t val)
{
	if (pin > MAXPINS) return;

	/* set or clear the apprporiate port bit */
	if (pinMap[pin][0] == 0) {
		// pin is on Port B
		if (val == 0) {
			/* clear the pin */
			VIA_PORTB = VIA_PORTB & ~pinMap[pin][1];
		} else {
			/* set the pin */
			VIA_PORTB = VIA_PORTB | pinMap[pin][1];
		}
	} else {
		// pin is on Port A
		if (val == 0) {
			/* clear the pin */
			VIA_PORTA = VIA_PORTA & ~pinMap[pin][1];
		} else {
			/* set the pin */
			VIA_PORTA = VIA_PORTA | pinMap[pin][1];
		}
	}
}
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

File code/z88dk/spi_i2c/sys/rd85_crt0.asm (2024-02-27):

; CRT0 module for the RetroDuino-8085 board
;
; Based on a configurable CRT for bare-metal: z80_crt0.asm
; as well as micro8085_crt0.asm by Anders Hjelm
;
; WARNING: Beyond hear be dragons, lots of dragons ...

    MODULE rd85_crt0 

;------------------------------------------------------------------------------
; Include zcc_opt.def to find out information about us
;------------------------------------------------------------------------------

    defc    crt0 = 1
    INCLUDE "zcc_opt.def"
	
;------------------------------------------------------------------------------
; Some general scope declarations
;------------------------------------------------------------------------------

    EXTERN    _main           ;main() is always external to crt0 code

	PUBLIC fputc_cons_native
	PUBLIC _fputc_cons_native

	PUBLIC fgetc_cons
	PUBLIC _fgetc_cons

; Definitions of the SCC2691 UART
DEFC	UART_BASE      = 00h
DEFC	UART_MODE_REG  = UART_BASE
DEFC	UART_CLK_REG   = UART_BASE + 1
DEFC	UART_STAT_REG  = UART_BASE + 1
DEFC	UART_CMD_REG   = UART_BASE + 2
DEFC	UART_TX_REG	   = UART_BASE + 3
DEFC	UART_RX_REG    = UART_BASE + 3
DEFC	UART_ISTAT_REG = UART_BASE + 5
DEFC	UART_IMASK_REG = UART_BASE + 5
DEFC	UART_CT_HI_REG = UART_BASE + 6
DEFC	UART_CT_LO_REG = UART_BASE + 7

	defc    CRT_ORG_CODE = 0x0000
	defc    CRT_ORG_DATA = 0x8000
	defc    CRT_ORG_BSS  = 0x8000
	
	defc	RAM_TOP		 = 0xFFF0
	
	defc    REGISTER_SP = RAM_TOP
	defc    CLIB_EXIT_STACK_SIZE = 0

	defc    __CPU_CLOCK = 5529600	; half of 11.0592MHz

    INCLUDE "crt/classic/crt_rules.inc"
	
    org    	CRT_ORG_CODE
rst0:
	lxi		sp,__register_sp
	jmp		start 

	defs    $08-ASMPC
rst1:
	ret                     ; RST1 not used

	defs    $10-ASMPC
rst2:
	ret                     ; RST2 not used

	defs    $18-ASMPC
rst3:
	ret                     ; RST3 not used

	defs    $20-ASMPC
rst4:
	ret                     ; RST4 not used

	defs    $24-ASMPC
trap:
	ret                     ; TRAP not used

	defs    $28-ASMPC
rst5:
	ret                     ; RST5 not used

	defs    $2C-ASMPC
rst55:
	ret                     ; RST5.5 not used

	defs    $30-ASMPC
rst6:
	ret                     ; RST6 not used

	defs    $34-ASMPC
rst65:
	ret                     ; RST6.5 not used
		
	defs    $38-ASMPC
rst7:
	ret                     ;RST7 not used

	defs    $3C-ASMPC
rst75:	
	jmp		uart_isr        ; RST7.5 wired to SCC2691 INT pin via GAL
	
;------------------------------------------------------------------------------
;------------------------------------------------------------------------------
start:
    INCLUDE "crt/classic/crt_init_atexit.asm"
	call	tgt_init
	call    crt0_init_bss
	call    _main           ; void main(void) so no args or retval

	lxi		h,exitmsg
	call	outstr
infloop:
	jmp     infloop         ; stay here in infinte loop

;------------------------------------------------------------------------------
; target specific initialisation
;------------------------------------------------------------------------------
tgt_init:

	; setup the SCC2691 UART for 19200,8,N,1
	mvi		a,10h			; load the RESET MR POINTER command 
	out		UART_CMD_REG	; write to COMMAND REGISTER
	mvi		a,13h			; 8 DATA BITS + NO PARITY 
	out		UART_MODE_REG	; write to MODE REGISTER #1
	mvi		a,07h			; 1 STOP BIT 
	out		UART_MODE_REG	; write to MODE REGISTER #2
	MVI 	A,0f8h		 	; BRG Set 2, Timer = CLK/16 & Power Down OFF
	OUT 	04h				; write to AUX CTRL REGISTER
	MVI		A,11001100b		; 19200 BAUD for RX & TX 
	out		UART_CLK_REG	; write to CLOCK SELECT REGISTER
	mvi		a,10h			; enable counter/timer interrupt
	out		UART_IMASK_REG	; write to INTERRUPT MASK REGISTER
	mvi		a,05h			; enable TX & RX
	out		UART_CMD_REG	; write to COMMAND REGISTER

	; configure the SCC2691 UART timer for interrupts every
	; 20 milliseconds and start it running
	mvi		a,09h
	out		UART_CT_HI_REG
	mvi		a,0h
	out		UART_CT_LO_REG
	mvi		a,080h
	out		UART_CMD_REG	; write to COMMAND REGISTER
	
	; enable RST7.5 interrupt
	mvi		a, 1Bh
	sim
	
	ret

;------------------------------------------------------------------------------
; output a null terminted string - HL points to 1st character
; don't bother preserving any registers as we're done.
outstr:
	mov		a,m				; get character
	inx		h				; increment ptr to next char
	ana		a				; is it NULL?
	rz						; if yes, then end of mesaage
	mov		b,a				; save char
outstr1:
	in		UART_STAT_REG	; get UART status
	ani 	04h				; test for TxRDY = 1
	jz		outstr1			; not ready - try again
	mov		a,b				; restore char
	out		UART_TX_REG		; write char
	jmp		outstr			; go back for next xhar

;------------------------------------------------------------------------------
; send a character/byte to the UART transmit register
; will wait for TX buffer to empty
fputc_cons_native:
_fputc_cons_native:
    pop     bc  ; return address
    pop     hl  ; character to print in l
    push    hl
    push    bc
	
	mov		a,l			; get the byte to transmit
	cmp		0AH			; is it a linefeed?
    jnz		txl			; not an LF so just print it
    mvi     l,0DH       ; is LF so output a CR first
    call    txl
    mvi     l,0AH       ; then output the LF	
.txl
	in		UART_STAT_REG
	ani		04h		; Test for TxRDY = 1
	jz		txl		; TX not empty - check again
    mov     a,l
    out     UART_TX_REG
    ret

;------------------------------------------------------------------------------
; get a character/byte from the UART receive register
; returns data in L
; will wait until a character/byte is available
fgetc_cons:
_fgetc_cons:
.rxl
	in		UART_STAT_REG
	ani		01h		; Test for RxRDY = 1
	jz		rxl		; Rx buffer empty - check again
	in		UART_RX_REG
    mov     l,a     ;Return the result in hl
    mvi     h,0
    ret

;------------------------------------------------------------------------------
; UART interrupt handler
; currently just the system tick generated from the SCC2691 timer

	EXTERN	_sysTick
	
uart_isr:
	; increment the system tick counter
	push	h
	lhld	_sysTick
	inx		h
	shld	_sysTick
	pop		h
	
	; clear the interrupt flag in the SCC2691 UART
	push	psw
	mvi		a,$90
	out		UART_CMD_REG
	
	; clear the RST7.5 flip flop
	mvi		a,10h
	sim
	
	pop		psw
	ei
	ret
	
exitmsg:
	defb	10,13,"** Exit from main().",10,13,0
	
    INCLUDE "crt/classic/crt_runtime_selection.asm" 
    INCLUDE	"crt/classic/crt_section.asm"

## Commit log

2024-01-25 Added PCB information
    PCB details have been added along with amendments to the README file.
    [0025_8085_UNO_Board_W65C22_v2.kicad_pcb, 0025_8085_UNO_Board_W65C22_v2.kicad_sch, BOM.csv]
2024-01-26 added LED flasher test program
2024-01-27 correction for SPI & I2C
2024-01-28 added second LEDTest code
    New LEDTest code that demonstrates how to run completely in RAM with MON85 switched out.
2024-01-28 Updated MON85 & LEDTest2
    MON85 now includes the ROM disable and JMP 0x0000 instructions. LEDTest2 changed to remove this code as it's now in MON85.
2024-02-16 Added assembly step
2024-02-27 added SPI, I2C & sys tick functionality
